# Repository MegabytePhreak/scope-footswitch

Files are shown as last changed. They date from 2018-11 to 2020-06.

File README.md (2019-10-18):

SCOPE-FOOTSWITCH
=================

STM32F401 based oscilloscope-footswitch interface using USBTMC.

Hardware is licensed CC-BY-SA-4.0
Software is GPLv3 for easy license compatibility with ChibiOS

Links:
* [Hackaday Coverage](https://hackaday.com/2018/12/02/keep-both-hands-on-the-probes-with-this-oscilloscope-footswitch/)
* [Initial Announcement](https://twitter.com/roukemap/status/1066811243237904384)
* [Rev.2 Batch](https://twitter.com/roukemap/status/1068734964215115776)
* [Custom Panels](https://twitter.com/roukemap/status/1072344658313908224)

Tools:

Other versions may work, this is just what is currently tested

HW:
* KiCAD 5.0.1

SW:
* arm-none-eabi-gcc (GNU Tools for ARM Embedded Processors 7-2018-q2-update) 7.3.1 20180622 (release) [ARM/embedded-7-branch revision 261907]
* GNU gdb (GNU Tools for ARM Embedded Processors 7-2018-q2-update) 8.1.0.20180315-git
* ChibiOS-RT with community USB Host framework
* libopencm3 and DFU code from BlackMagicProbe

This repo uses several submodules, make sure they are up to date.
After checking out the kicad-library repo, make sure to cd to it and run make to generate the actual KiCAD libraries.

SW Build Process:
1. Make sure the arm-none-eabi toolchain is on your path: `which arm-none-eabi-gcc`
2. Pre-build the libopencm3 library: `cd sw/ext/libopencm3 && make -j && cd ../../..`
3. Build the bootloader: `cd sw/bootloader && make -j && cd ../..`
4. Build the main application: `cd sw/scope-footswitch && make -j && cd ../..`

SW Programming process:
1. Connect SWD debugger (e.g. blackmagicprobe) to hardware
2. Connect micro-usb from pc to hardware
3. `cd sw/bootloader`
4. `./flash.sh`
5. Power cycle hardware, holding down the front panel button to force entry to the bootloader
6. `cd ../scope-footswitch`
7. `./dfu.sh`

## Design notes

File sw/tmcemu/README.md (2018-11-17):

TMCEMU
=======

STM32F072B-DISCO based USBTMC device with oscilloscope emulation

Tools:

* arm-none-eabi-gcc (GNU Tools for Arm Embedded Processors 7-2018-q2-update) 7.3.1 20180622 (release) [ARM/embedded-7-branch revision 261907]
* GNU gdb (GNU Tools for Arm Embedded Processors 7-2018-q2-update) 8.1.0.20180315-git
* ChibiOS-RT
* scpi-parser

This repo uses several submodules, make sure they are up to date.

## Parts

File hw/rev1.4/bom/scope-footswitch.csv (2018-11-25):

Source: | C:\Users\Megabytephreak\Code\scope-footswitch\hw\scope-footswitch.sch
Date: | 2018-11-19 0:04
Tool: | Eeschema (5.0.0)
Generator: | C:\Users\Megabytephreak\Code\scope-footswitch\hw\kicad-library\scripting/bom.py
Component Count: | 97
Item | Qty | Reference(s) | Value | LibPart | Footprint | Datasheet | BOM_IGNORE | COLOR | CREATED_ON | Capacitance | ComponentLink1Description | ComponentLink2Description | ComponentLink2URL | DNP | Description | Dielectric | Frequency | IF | Id | MANUFACTURER_PART_NUMBER | Manufacturer | NUMBER | Package | Power | Resistance | Supplier 1 | Supplier 2 | Supplier Part Number 1 | Supplier Part Number 2 | Tolerance | Type | VF | VR | Vdss | Vgsth | Voltage
1 | 18 | C1, C2, C3, C4, C7, C8, C13, C14, C15, C16, C17, C18, C19, C21, C22, C23, C27, C29 | C00001 | capacitors:C00001 | footprints:C_0402_1005M | http://search.murata.co.jp/Ceramy/image/img/PDF/ENG/GRM155R61A104KA01.pdf |  |  | 02/17/11 00:00:00 | 100n | Datasheet |  |  |  | CAP CER .1UF 10V 10% X5R 0402 | X5R |  |  |  | GRM155R61A104KA01D | Murata |  | 402 |  |  | Digi-key | Digi-key | 490-1318-2-ND | 490-1318-1-ND | ±10% |  |  |  |  |  | 10V
2 | 3 | C6, C20, C28 | C00002 | capacitors:C00002 | footprints:C_0603_1608M | http://search.murata.co.jp/Ceramy/image/img/PDF/ENG/GRM188R61A105KA61.pdf |  |  | 02/18/11 00:00:00 | 1µ | Datasheet |  |  |  | CAP CER 1.0UF 10V 10% X5R 0603 | X5R |  |  |  | GRM188R61A105KA61D | Murata |  | 603 |  |  | Digi-key | Digi-key | 490-1543-2-ND | 490-1543-2-ND | ±10% |  |  |  |  |  | 10V
3 | 2 | C9, C11 | C00033 | capacitors:C00033 | footprints:C_0402_1005M | http://search.murata.co.jp/Ceramy/image/img/A01X/G101/ENG/GRM1555C1H220JA01-01.pdf |  |  | 2008-04-17 0:00 | 22p | Spec Sheet |  |  |  | CAP CER 22PF 50V C0G/NP0 0402 | C0G |  |  |  | GRM1555C1H220JA01J | Murata |  | 402 |  |  | Digi-Key | Digi-Key | 490-11382-2-ND | 490-11382-1-ND | ±5% |  |  |  |  |  | 50V
4 | 1 | C10 | C00004 | capacitors:C00004 | footprints:C_0805_2012M | http://search.murata.co.jp/Ceramy/image/img/PDF/ENG/GRM21BR60J106ME19.pdf |  |  | 02/18/11 00:00:00 | 10µ | Datasheet |  |  |  | CAP CER 10UF 6.3V 20% X5R 0805 | X5R |  |  |  | GRM21BR60J106ME19L | Murata |  | 805 |  |  | Digi-key | Digi-key | 490-1718-2-ND | 490-1718-1-ND | ±20% |  |  |  |  |  | 6.3V
5 | 1 | C12 | C00007 | capacitors:C00007 | footprints:C_0603_1608M | http://search.murata.co.jp/Ceramy/image/img/PDF/ENG/GRM188R60J475ME19.pdf |  |  | 09/23/11 00:00:00 | 4u7 | Datasheet |  |  |  | CAP CER 4.7UF 6.3V X5R 0603 | X5R |  |  |  | GRM188R60J475ME19D | Murata |  | 603 |  |  | Digi-key | Digi-key | 490-5421-2-ND | 490-5421-1-ND | ±20% |  |  |  |  |  | 6.3V
6 | 1 | C24 | C00003 | capacitors:C00003 | footprints:CRADIAL_6.3x11.2_2.5 | http://industrial.panasonic.com/www-cgi/jvcr13pz.cgi?E+PZ+3+ABA0012+ECA1EM101+7+WW |  |  | 02/18/11 00:00:00 | 100µ | Component Page |  |  |  | CAP 100UF 25V ALUM LYTIC RADIA | Electrolytic |  |  |  | ECA-1EM101 | Panasonic |  | Radial |  |  | Digi-key |  | P5152-ND |  | ±20% |  |  |  |  |  | 25V
7 | 2 | C25, C26 | C00027 | capacitors:C00027 | footprints:C_0402_1005M | http://www.yageo.com/documents/recent/UPY-GP_NP0_16V-to-50V_10.pdf |  |  | 2008-02-18 0:00 | 4n7 | Datasheet |  |  |  | CAP CER 4700PF 50V X7R 0402 | X7R |  |  |  | 8.85012E+11 | Wurth |  | 402 |  |  | Digi-Key | Digi-Key | 732-7560-1-ND | 732-7560-2-ND | ±10% |  |  |  |  |  | 50V
8 | 1 | D2 | LED00006 | leds:LED00006 | footprints:LED_3535_NEOPIXEL_MINI | https://cdn-shop.adafruit.com/product-files/2686/SK6812MINI_REV.01-1-2.pdf |  | RGB | 04/29/16 00:00:00 |  | Datasheet |  |  |  | LED RGB, ADDRESSABLE, 3535 |  |  |  |  | SK6812MINI | DONGGUANG OPSCO OPTOELECTRONICS CO., LTD |  | 3535 |  |  | Digi-Key | Adafruit | 1528-1541-ND | 2686 |  |  |  |  |  |  | 5V
9 | 3 | D3, D4, D5 | D00003 | diodes:D00003 | footprints:SOT_6_950_2900X1600X1100 | http://www.st.com/web/en/resource/technical/document/datasheet/CD00047494.pdf |  |  | 07/18/15 00:00:00 |  | Datasheet |  |  |  | TVS DIODE 5.25VWM 17VC SOT23-6 |  |  | - |  | USBLC6-4SC6 | ST |  |  | - |  | Digi-Key |  | 497-4492-1-ND |  |  | TVS ARRAY | - | 6
10 | 1 | D6 | D00006 | diodes:D00006 | footprints:SOT_3_950_2900X1300X1000_ONSEMI | http://www.onsemi.com/pub/Collateral/BAT54CLT1-D.PDF |  |  | 09/23/18 00:00:00 |  | Datasheet |  |  |  | DIODE ARRAY SCHOTTKY 30V SOT23-3 |  |  | 200mA |  | BAT54CLT3G | ON Semiconductior |  |  | 225mQ |  | Digi-Key |  | BAT54CLT3GOSCT-ND |  |  | Array | 300mV @ 1MA | 30V
11 | 1 | J1 | CN00050 | connectors:CN00050 | footprints:J_CUI_SJ1-3533NG | https://www.cui.com/product/resource/digikeypdf/sj1-353xng.pdf |  |  | 07/29/18 00:00:00 |  | Drawing |  |  |  | CONN JACK STEREO 3.5MM R/A |  |  |  |  | SJ1-3533NG | CUI |  |  |  |  | Digi-Key |  | CP1-3533NG-ND
12 | 1 | J2 | CN00049 | connectors:CN00049 | footprints:J_AMPHENOL_UE27AC54100 | https://www.amphenolcanada.com/ProductSearch/drawings/AC/UE27ACX4X0X.pdf |  |  | 07/28/18 00:00:00 |  | Drawing |  |  |  | CONN RCPT USB TYPE A R/A GOLD |  |  |  |  | UE27AC54100 | Amphenol |  |  |  |  | Digi-Key |  | UE27AC54100-ND
13 | 1 | J3 | CN00023 | connectors:CN00023 | footprints:J_FCI_10118194 | http://portal.fciconnect.com/Comergent//fci/drawing/10118194.pdf |  |  | 2001-02-15 0:00 |  | Drawing |  |  |  | CONN USB MICRO B RECPT SMT R/A |  |  |  |  | 10118194-0001LF | FCI |  |  |  |  | Digi-Key |  | 609-4618-1-ND
14 | 1 | P1 | CN00052 | connectors:CN00052 | footprints:P_FCI_68000-206 | http://portal.fciconnect.com/Comergent//fci/drawing/68000.pdf |  |  | 07/31/18 00:00:00 |  | Drawing |  |  |  | BERGSTIK II 6POS .100" SR STRAIGHT |  |  |  |  | 68000-206HLF | FCI |  |  |  |  | Digi-Key |  | 609-3256-ND
15 | 1 | P2 | CN00051 | connectors:CN00051 | footprints:P_CNC_3221-10-0300-00 | http://cnctech.us/pdfs/3221-XX-0300-00.pdf |  |  | 07/30/18 00:00:00 |  | Drawing |  |  |  | IDC BOX HEADER .050" 10 POS |  |  |  |  | 3221-10-0300-00 | CNC Tech |  |  |  |  | Digi-Key |  | 1175-1735-ND
16 | 1 | Q1 | Q00002 | transistors:Q00002 | footprints:SOT_6_650_2150X1300x1100_DIODES | http://www.diodes.com/datasheets/DMN63D8LDW.pdf |  |  | 2007-08-15 0:00 |  | Datasheet |  |  |  | MOSFET 2N-CH 30V 220MA SOT363 |  |  |  | 220mA | DMN63D8LDW-7 | Diodes Inc | 2 |  | 300mW |  | Digi-Key |  | DMN63D8LDW-7CT-ND |  |  | N-FET |  |  | 30V | 1.5V
17 | 18 | R1, R4, R5, R8, R13, R18, R21, R22, R23, R24, R25, R26, R27, R28, R30, R32, R33, R41 | R00014 | resistors:R00014 | footprints:R_0402_1005M | http://www.yageo.com/documents/recent/PYu-RC0402_51_RoHS_L_6.pdf |  |  | 09/23/11 00:00:00 |  | Series Datasheet |  |  |  | RES 10.0K OHM 1/16W 1% 0402 SMD |  |  |  |  | RC0402FR-0710KL | Yageo |  | 402 | 1/16W | 10K | Digi-key | Digi-key | 311-10.0KLRTR-ND | 311-10.0KLRCT-ND | 1% | Thick Film
18 | 3 | R2, R3, R35 | R00016 | resistors:R00016 | footprints:R_0402_1005M | http://www.yageo.com/documents/recent/PYu-RC0402_51_RoHS_L_6.pdf |  |  | 09/25/11 00:00:00 |  | Series Datasheet |  |  |  | RES 100K OHM 1/16W 5% 0402 SMD |  |  |  |  | RC0402JR-07100KL | Yageo |  | 402 | 1/16W | 100K | Digi-key | Digi-key | 311-100KJRTR-ND | 311-100KJRCT-ND | 1% | Thick Film
19 | 1 | R7 | R00056 | resistors:R00056 | footprints:R_0402_1005M | http://www.yageo.com/documents/recent/PYu-RC0402_51_RoHS_L_6.pdf |  |  | 2008-05-17 0:00 |  | Series Datasheet |  |  |  | RES SMD 15K OHM 1% 1/16W 0402 |  |  |  |  | RC0402FR-0715KL | Yageo |  | 402 | 1/16W | 15K | Digi-key | Digi-key | 311-15K0LRTR-ND | 311-15K0LRCT-ND | 1% | Thick Film
20 | 1 | R9 | R00037 | resistors:R00037 | footprints:R_0402_1005M | http://www.yageo.com/documents/recent/PYu-RC0402_51_RoHS_L_6.pdf |  |  | 07/24/17 00:00:00 |  | Series Datasheet |  |  |  | RES 240 OHM 1/16W 1% 0402 SMD |  |  |  |  | RC0402FR-07240R1L | Yageo |  | 402 | 1/16W | 240R | Digi-key | Digi-key | 311-240LRTR-ND | 311-240LRCT-ND | 1% | Thick Film
21 | 1 | R14 | R00009 | resistors:R00009 | footprints:R_0402_1005M | http://www.yageo.com/documents/recent/PYu-RC0402_51_RoHS_L_6.pdf |  |  | 08/21/11 00:00:00 |  | Series Datasheet |  |  |  | RES 56K OHM 1/16W 5% 0402 SMD |  |  |  |  | RC0402JR-0756KL | Yageo |  | 402 | 1/16W | 56K | Digi-key | Digi-key | 311-56KJRTR-ND | 311-56KJRCT-ND | 5% | Thick Film
22 | 2 | R19, R20 | R00011 | resistors:R00011 | footprints:R_0402_1005M | http://www.yageo.com/documents/recent/PYu-RC0402_51_RoHS_L_6.pdf |  |  | 09/23/11 00:00:00 |  | Series Datasheet |  |  |  | RES 100 OHM 1/16W 1% 0402 SMD |  |  |  |  | RC0402FR-07100RL | Yageo |  | 402 | 1/16W | 100R | Digi-key | Digi-key | 311-100LRTR-ND | 311-100LRCT-ND | 1% | Thick Film
23 | 2 | R29, R31 | R00080 | resistors:R00080 | footprints:R_0603_1608M | https://www.seielect.com/Catalog/SEI-RMCF_RMCP.pdf |  |  | 09/20/18 00:00:00 |  | Series Datasheet |  |  |  | RES 64.9 OHM 1% 1/10W 0603 |  |  |  |  | RMCF0603FT64R9 | Stackpole |  | 603 | 1/10W | 64R9 | Digi-key | Digi-key | RMCF0603FT64R9TR-ND | RMCF0603FT64R9CT-ND | 1% | Thick Film
24 | 2 | R39, R40 | R00008 | resistors:R00008 | footprints:R_0402_1005M | http://www.yageo.com/documents/recent/PYu-RC0402_51_RoHS_L_6.pdf |  |  | 08/20/11 00:00:00 |  | Series Datasheet |  |  |  | RES 1.0M OHM 1/16W 5% 0402 SMD |  |  |  |  | RC0402JR-071ML | Yageo |  | 402 | 1/16W | 1M | Digi-key | Digi-key | 311-1.0MJRTR-ND | 311-1.0MJRCT-ND | 5% | Thick Film
25 | 1 | R42 | R00001 | resistors:R00001 | footprints:R_0402_1005M | http://www.seielect.com/Catalog/SEI-RMC.pdf |  |  | 02/17/11 00:00:00 |  | Series Datasheet |  |  |  | RES 0.0 OHM 1/16W 0402 SMD |  |  |  |  | RMCF0402ZT0R00 | Stackpole Electronics |  | 402 | 1/16W | 0R | Digi-key | Digi-key | RMCF0402ZT0R00TR-ND | RMCF0402ZT0R00CT-ND |  | Thick Film
26 | 1 | SW1 | M00027 | misc:M00027 | footprints:SW_NKK_G13AV | http://www.nkkswitches.com/pdf/Gtoggles.pdf | 0 |  | 07/18/29 00:00:00 |  | Series Datasheet |  |  |  | SWITCH TOGGLE SPDT 0.4VA 28V |  |  |  |  | G13AV | NKK Switches |  |  |  |  | Digi-Key |  | 360-1770-ND
27 | 1 | SW2 | M00012 | misc:M00012 | footprints:SW_TL1105JA | http://spec_sheets.e-switch.com/specs/P010205.pdf | 0 |  | 2007-05-15 0:00 |  | Drawing | Series Datasheet | https://www.e-switch.com/system/asset/product_line/data_sheet/140/TL1105.pdf |  | SWITCH TACTILE SPST-NO 0.05A 12V |  |  |  |  | TL1105JAF160Q | E-Switch |  |  |  |  | Digi-Key |  | EG1863-ND
28 | 1 | SW3 | M00026 | misc:M00026 | footprints:SW_NKK_G12JVCF | http://www.nkkswitches.com/pdf/gtogglesilluminated.pdf | 0 |  | 07/29/18 00:00:00 |  | Series Datasheet |  |  |  | SWITCH ILLUMINATED TOGGLE SPDT 0.4VA 28V |  |  |  |  | G12JVCF | NKK Switches |  |  |  |  | Digi-Key |  | 360-1765-ND
29 | 1 | U1 | U00054 | ics:U00054 | footprints:SOT_5_950_2900X1600X1100_DIODES | http://www.diodes.com/_files/datasheets/74AHCT1G125.pdf |  |  | 04/29/16 00:00:00 |  | Datasheet |  |  |  | 74AHCT1G125W5-7 |  |  |  |  | 74AHCT1G125W5-7 | Diodes |  |  |  |  | Digi-Key |  | 74AHCT1G125W5-7DICT-ND
30 | 2 | U2, U8 | U00086 | ics:U00086 | footprints:SOT_6_950_2800x1600x110_DIODES_SOT26 | https://www.diodes.com/assets/Datasheets/AP255x.pdf |  |  | 07/29/18 00:00:00 |  | Datasheet |  |  |  | IC PD SW CURR LIMIT SOT26 |  |  |  |  | AP2553AW6-7 | Diodes |  |  |  |  | Digi-Key |  | AP2553AW6-7DICT-ND
31 | 1 | U5 | U00049 | ics:U00049 | footprints:SOT_5_950_2900X1600X1100_DIODES | http://www.diodes.com/datasheets/AP2138_9.pdf |  |  | 2001-03-15 0:00 |  | Datasheet |  |  |  | IC REG LDO 3.3V 0.25A SOT25 |  |  |  |  | AP2139AK-3.3TRG1 | Diodes |  |  |  |  | Digi-Key |  | AP2139AK-3.3TRG1DICT-ND
32 | 1 | U6 | U00084 | ics:U00084 | footprints:QFN_48_500_7000X7000X600_ST | http://www.st.com/content/ccc/resource/technical/document/datasheet/9e/50/b1/5a/5f/ae/4d/c1/DM00086815.pdf/files/DM00086815.pdf/jcr:content/translations/en.DM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 |  |  | 07/28/18 00:00:00 |  | Datasheet |  |  |  | IC MCU 32BIT 128KB FLASH 48QFPN |  |  |  |  | STM32F401CBU6 | ST |  |  |  |  | Digi-Key |  | 497-17425-ND
33 | 1 | U7 | U00085 | ics:U00085 | footprints:MSOP_10_500_3000X3000X1100_ONSEMI | https://www.fairchildsemi.com/datasheets/FS/FSUSB42.pdf |  |  | 07/28/18 00:00:00 |  | Datasheet |  |  |  | IC USB SWITCH DPDT 10MSOP |  |  |  |  | FSUSB42MUX | ONSEMI |  |  |  |  | Digi-Key |  | FSUSB42MUXCT-ND
34 | 1 | Y1 | Y00015 | crystals:Y00015 | footprints:XTAL_2_5000X3200X1300_ABRACON | https://abracon.com/Resonators/abm3.pdf |  |  | 07/29/18 00:00:00 | 18pF | Datasheet |  |  |  | CRYSTAL 8.0000MHZ 18PF SMD |  | 8 MHz |  |  | ABM3-8.000MHZ-D2Y-T | Abracon |  | 5mm x 3.2mm |  |  | Digi-Key |  | 535-10630-1-ND |  | 20ppm | Crystal
35 | 1 | C5 | C00001 | capacitors:C00001 | footprints:C_0402_1005M | http://search.murata.co.jp/Ceramy/image/img/PDF/ENG/GRM155R61A104KA01.pdf |  |  | 02/17/11 00:00:00 | 100n | Datasheet |  |  | DNP | CAP CER .1UF 10V 10% X5R 0402 | X5R |  |  |  | GRM155R61A104KA01D | Murata |  | 402 |  |  | Digi-key | Digi-key | 490-1318-2-ND | 490-1318-1-ND | ±10% |  |  |  |  |  | 10V
36 | 1 | D1 | D00006 | diodes:D00006 | footprints:SOT_3_950_2900X1300X1000_ONSEMI | http://www.onsemi.com/pub/Collateral/BAT54CLT1-D.PDF |  |  | 09/23/18 00:00:00 |  | Datasheet |  |  | DNP | DIODE ARRAY SCHOTTKY 30V SOT23-3 |  |  | 200mA |  | BAT54CLT3G | ON Semiconductior |  |  | 225mQ |  | Digi-Key |  | BAT54CLT3GOSCT-ND |  |  | Array | 300mV @ 1MA | 30V
37 | 5 | R6, R11, R15, R16, R17 | R00014 | resistors:R00014 | footprints:R_0402_1005M | http://www.yageo.com/documents/recent/PYu-RC0402_51_RoHS_L_6.pdf |  |  | 09/23/11 00:00:00 |  | Series Datasheet |  |  | DNP | RES 10.0K OHM 1/16W 1% 0402 SMD |  |  |  |  | RC0402FR-0710KL | Yageo |  | 402 | 1/16W | 10K | Digi-key | Digi-key | 311-10.0KLRTR-ND | 311-10.0KLRCT-ND | 1% | Thick Film
38 | 2 | R10, R12 | R00038 | resistors:R00038 | footprints:R_0402_1005M | http://www.yageo.com/documents/recent/PYu-RC0402_51_RoHS_L_6.pdf |  |  | 07/24/17 00:00:00 |  | Series Datasheet |  |  | DNP | RES 4.7K OHM 1/16W 1% 0402 SMD |  |  |  |  | RC0402FR-074K7L | Yageo |  | 402 | 1/16W | 4K7 | Digi-key | Digi-key | 311-4.7KTR-ND | 311-4.7KLRCT-ND | 1% | Thick Film
39 | 2 | R34, R37 | R00081 | resistors:R00081 | footprints:R_0402_1005M | https://www.seielect.com/Catalog/SEI-RMCF_RMCP.pdf |  |  | 09/30/18 00:00:00 |  | Series Datasheet |  |  | DNP | RES 1.5K OHM 1% 1/16W 0402 |  |  |  |  | RMCF0402FT1K50 | Stackpole |  | 402 | 1/16W | 1K5 | Digi-key | Digi-key | RMCF0402FT1K50TR-ND | RMCF0402FT1K50CT-ND | 1% | Thick Film
40 | 2 | R36, R38 | R00056 | resistors:R00056 | footprints:R_0402_1005M | http://www.yageo.com/documents/recent/PYu-RC0402_51_RoHS_L_6.pdf |  |  | 2008-05-17 0:00 |  | Series Datasheet |  |  | DNP | RES SMD 15K OHM 1% 1/16W 0402 |  |  |  |  | RC0402FR-0715KL | Yageo |  | 402 | 1/16W | 15K | Digi-key | Digi-key | 311-15K0LRTR-ND | 311-15K0LRCT-ND | 1% | Thick Film
41 | 1 | R43 | R00046 | resistors:R00046 | footprints:R_0402_1005M | http://www.yageo.com/documents/recent/PYu-RC0402_51_RoHS_L_6.pdf |  |  | 2008-01-17 0:00 |  | Series Datasheet |  |  | DNP | RES 10K OHM 1/16W 1% 0402 SMD |  |  |  |  | RC0402FR-0710KL | Yageo |  | 402 | 1/16W | 10K | Digi-key | Digi-key | 311-10.0KLRTR-ND | 311-10.0KLRCT-ND | 1% | Thick Film
42 | 1 | R44 | R00001 | resistors:R00001 | footprints:R_0402_1005M | http://www.seielect.com/Catalog/SEI-RMC.pdf |  |  | 02/17/11 00:00:00 |  | Series Datasheet |  |  | DNP | RES 0.0 OHM 1/16W 0402 SMD |  |  |  |  | RMCF0402ZT0R00 | Stackpole Electronics |  | 402 | 1/16W | 0R | Digi-key | Digi-key | RMCF0402ZT0R00TR-ND | RMCF0402ZT0R00CT-ND |  | Thick Film
43 | 1 | U3 | U00055 | ics:U00055 | footprints:SOIC_8_1270_4900X3900X1750 | http://www2.st.com/content/ccc/resource/technical/document/datasheet/b0/d8/50/40/5a/85/49/6f/DM00071904.pdf/files/DM00071904.pdf/jcr:content/translations/en.D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 |  |  | 04/29/16 00:00:00 |  | Datasheet |  |  | DNP | IC EEPROM 2KBIT 400KHZ 8SOIC |  |  |  |  | M24C02-FMN6TP | ST |  |  |  |  | Digi-Key |  | 497-15748-1-ND
44 | 1 | U4 | U00087 | ics:U00087 | footprints:SOT_5_950_2900X1600X1100_DIODES | https://www.diodes.com/assets/Datasheets/74AHCT1G08.pdf |  |  | 2008-05-18 0:00 |  | Datasheet |  |  | DNP | IC GATE AND 1CH 2-INP SOT25 |  |  |  |  | 74AHCT1G08W5-7 | Diodes |  |  |  |  | Digi-Key |  | 74AHCT1G08W5-7DICT-ND

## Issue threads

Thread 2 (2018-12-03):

Dictaphone footswitch

sbridger, 2018-12-03:
Look for Dictaphone footswitches. They commonly have 3 switches, and are very well designed for foot operation - better than the generic little metal single switch plate.

I have wired a couple up to old usb keyboard controllers to control production test software

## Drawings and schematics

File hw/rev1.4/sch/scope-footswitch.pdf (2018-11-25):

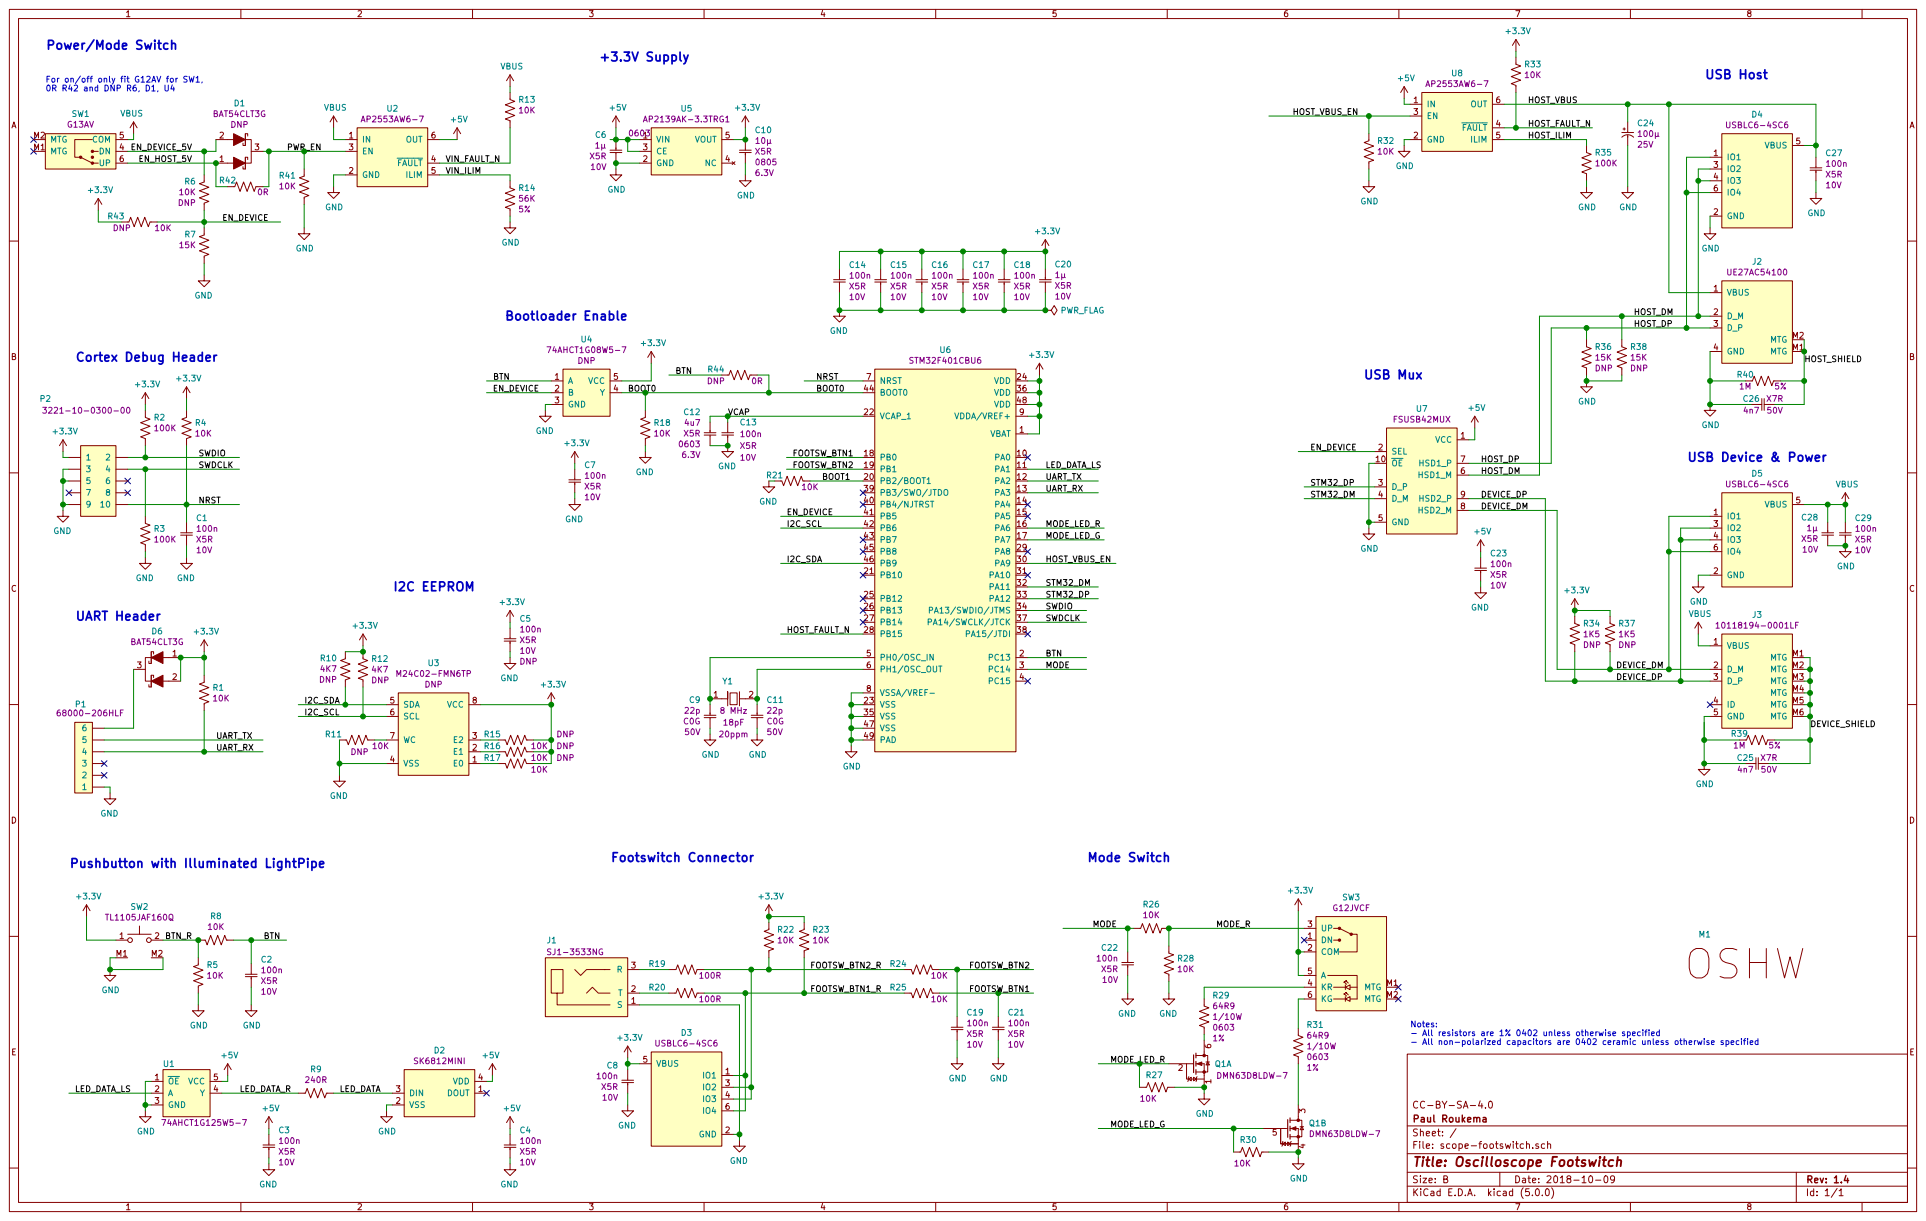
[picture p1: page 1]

For on/off only fit G12AV for SW1, 0R R42 and DNP R6, D1, U4 +3.3V

UART Header
HOST_FAULT_N Pushbutton with Illuminated LightPipe

Notes: - All resistors are 1% 0402 unless otherwise specified
- All non-polarized capacitors are 0402 ceramic unless otherwise specified

File: scope-footswitch.sch Sheet: / Paul Roukema CC-BY-SA-4.0

Id: 1/1 Title: Oscilloscope Footswitch

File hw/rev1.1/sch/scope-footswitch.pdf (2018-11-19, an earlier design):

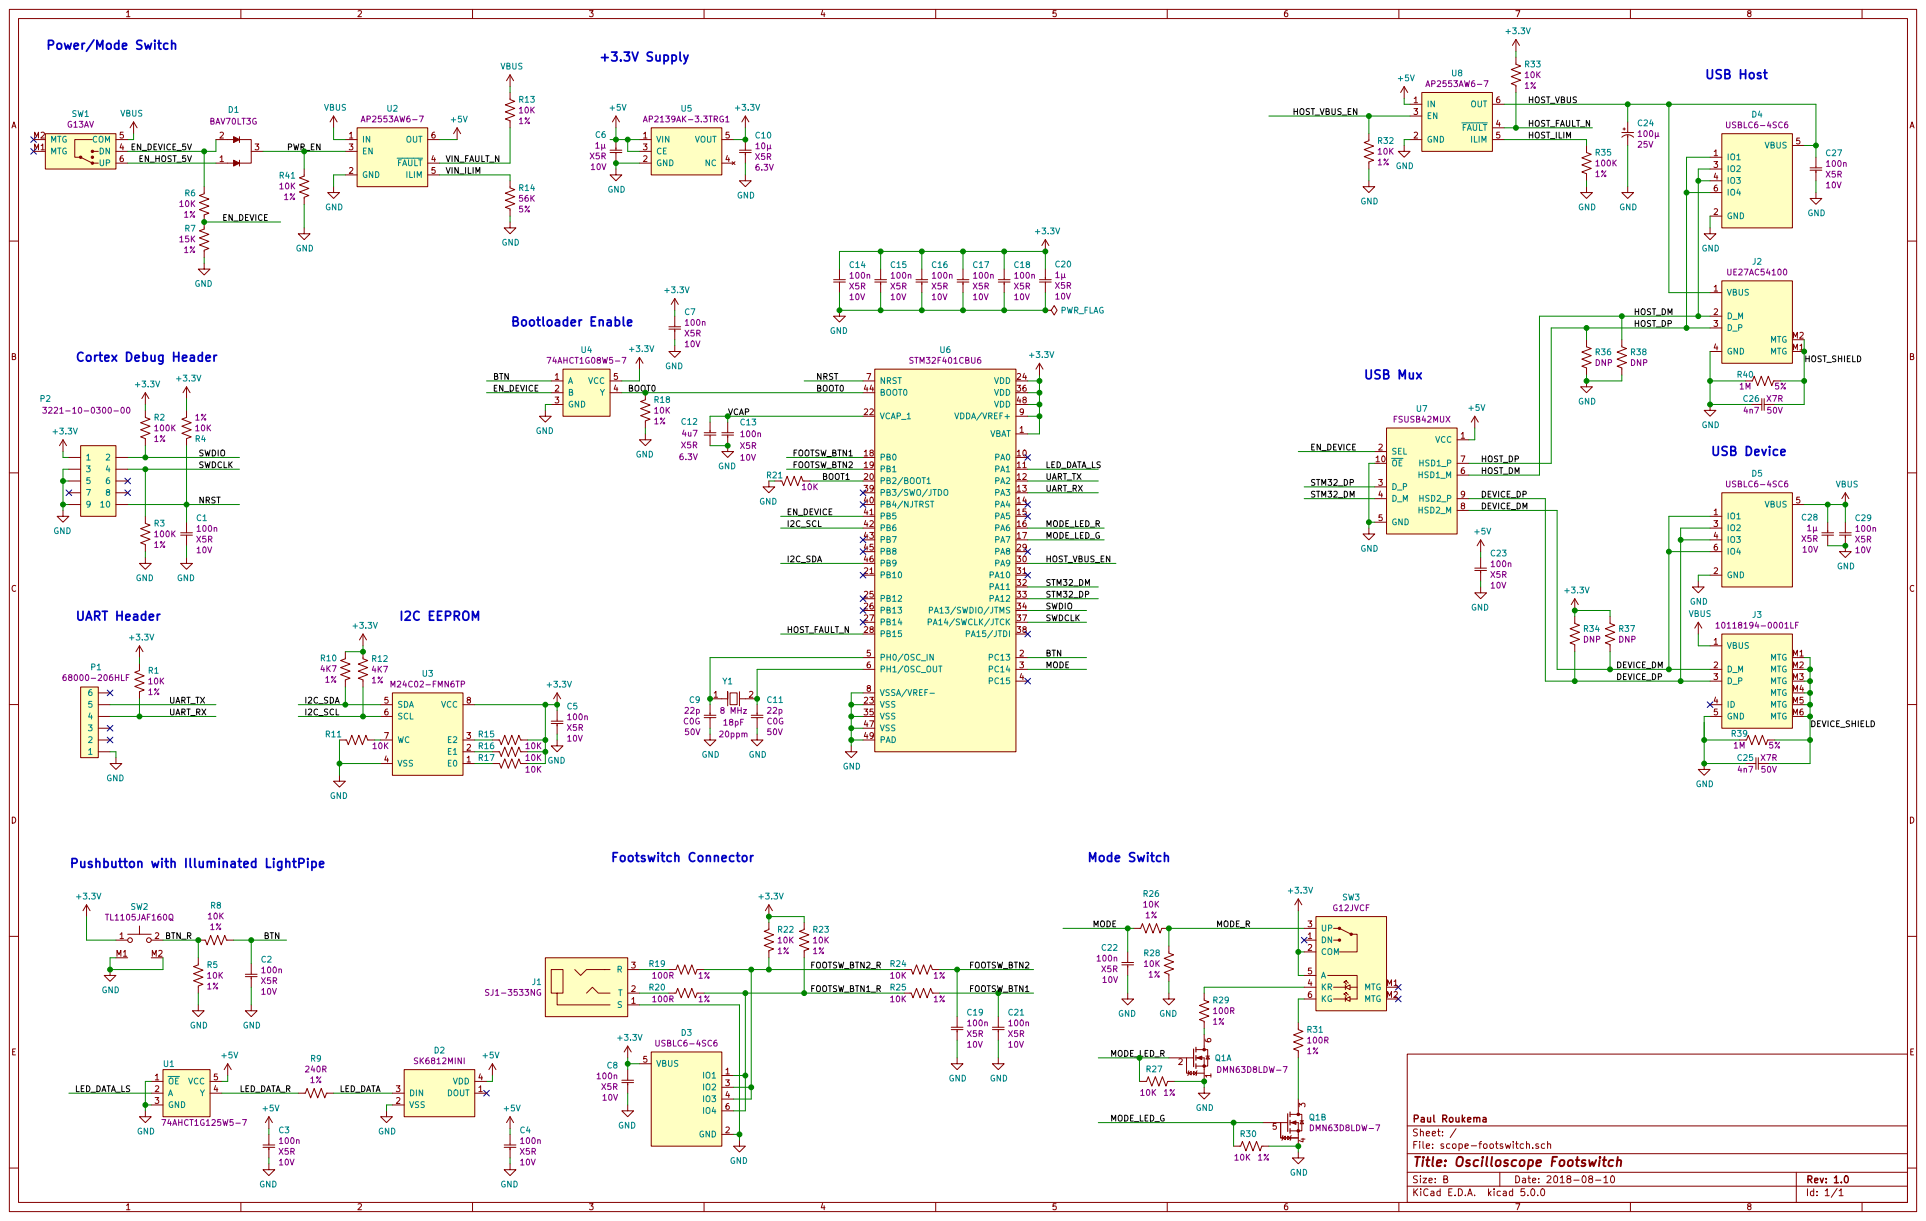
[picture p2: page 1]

UART Header
HOST_FAULT_N Pushbutton with Illuminated LightPipe

File: scope-footswitch.sch Sheet: / Paul Roukema

Id: 1/1 Title: Oscilloscope Footswitch

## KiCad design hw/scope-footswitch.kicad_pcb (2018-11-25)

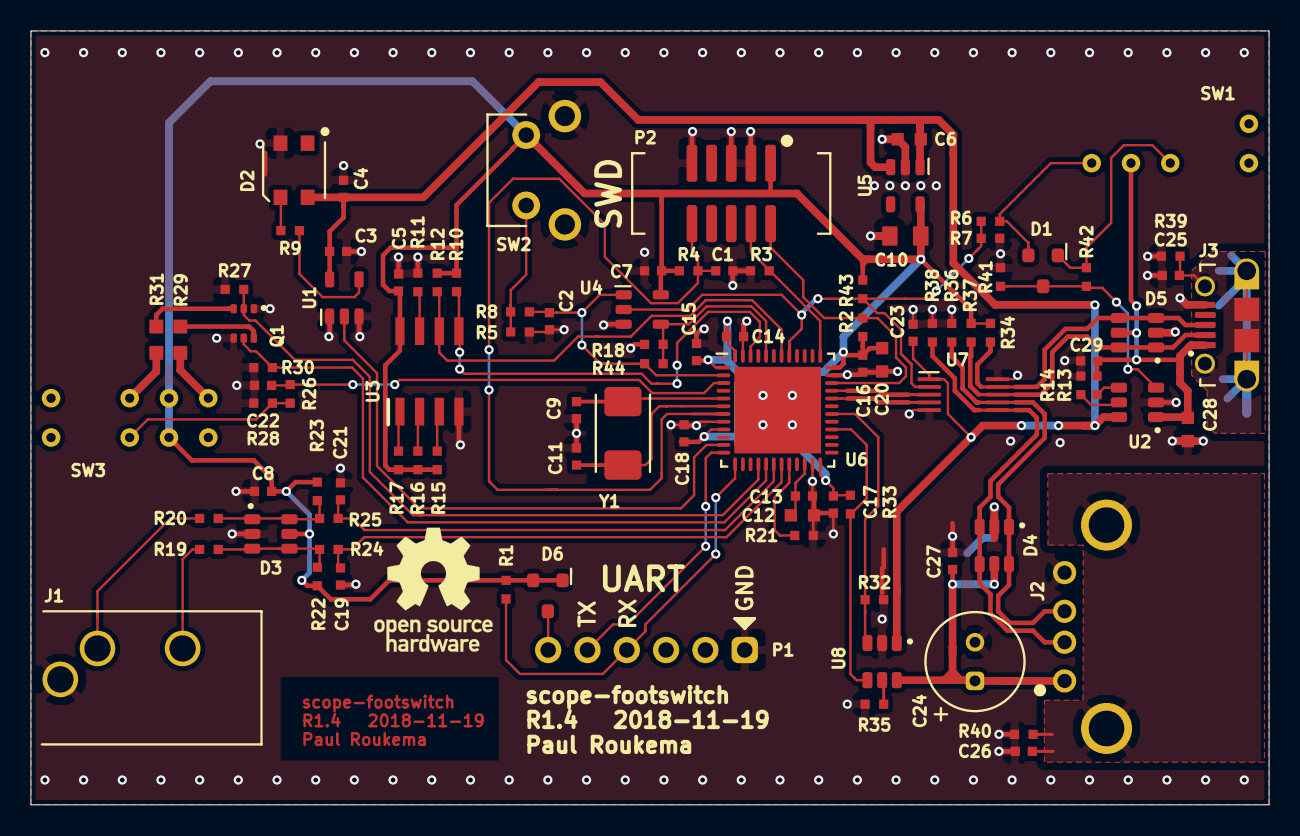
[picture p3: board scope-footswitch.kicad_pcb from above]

Board: 2 copper layers, 80.0 x 50.0 mm, 98 parts (0 on the bottom side), 58 nets.

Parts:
C1, C2, C3, C4, C5, C7, C8, C13, C14, C15, C16, C17, C18, C19, C21, C22, C23, C27, C29: C00001; C_0402_1005M
C6, C20, C28: C00002; C_0603_1608M
C9, C11: C00033; C_0402_1005M
C10: C00004; C_0805_2012M
C12: C00007; C_0603_1608M
C24: C00003; CRADIAL_6.3x11.2_2.5
C25, C26: C00027; C_0402_1005M
D1, D6: D00006; SOT_3_950_2900X1300X1000_ONSEMI
D2: LED00006; LED_3535_NEOPIXEL_MINI
D3, D4, D5: D00003; SOT_6_950_2900X1600X1100
J1: CN00050; J_CUI_SJ1-3533NG
J2: CN00049; J_AMPHENOL_UE27AC54100
J3: CN00023; J_FCI_10118194
M1: M00028; OSHW-Logo_7.5x8mm_SilkScreen
P1: CN00052; P_FCI_68000-206
P2: CN00051; P_CNC_3221-10-0300-00
Q1: Q00002; SOT_6_650_2150X1300x1100_DIODES
R1, R4, R5, R6, R8, R11, R13, R15, R16, R17, R18, R21, R22, R23, R24, R25, R26, R27, R28, R30, R32, R33, R41: R00014; R_0402_1005M
R2, R3, R35: R00016; R_0402_1005M
R7, R36, R38: R00056; R_0402_1005M
R9: R00037; R_0402_1005M
R10, R12: R00038; R_0402_1005M
R14: R00009; R_0402_1005M
R19, R20: R00011; R_0402_1005M
R29, R31: R00080; R_0603_1608M
R34, R37: R00081; R_0402_1005M
R39, R40: R00008; R_0402_1005M
R42, R44: R00001; R_0402_1005M
R43: R00046; R_0402_1005M
SW1: M00027; SW_NKK_G13AV
SW2: M00012; SW_TL1105JA
SW3: M00026; SW_NKK_G12JVCF
U1: U00054; SOT_5_950_2900X1600X1100_DIODES
U2, U8: U00086; SOT_6_950_2800x1600x110_DIODES_SOT26
U3: U00055; SOIC_8_1270_4900X3900X1750
U4: U00087; SOT_5_950_2900X1600X1100_DIODES
U5: U00049; SOT_5_950_2900X1600X1100_DIODES
U6: U00084; QFN_48_500_7000X7000X600_ST
U7: U00085; MSOP_10_500_3000X3000X1100_ONSEMI
Y1: Y00015; XTAL_2_5000X3200X1300_ABRACON

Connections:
+3V3: C5.1, C7.1, C8.1, C10.1, C14.1, C15.1, C16.1, C17.1, C18.1, C20.2, D3.5, D6.1, D6.2, P2.1, R1.1, R2.1, R4.1, R10.2, R12.1, R15.2, R16.2, R17.2, R22.1, R23.1, R33.1, R34.1, R37.1, R43.2, SW2.1, SW3.2, SW3.5, U3.8, U4.5, U5.5, U6.1, U6.9, U6.24, U6.36, U6.48
+5V: C3.1, C4.1, C6.2, C23.1, D2.4, U1.5, U2.6, U5.1, U5.3, U7.1, U8.1
/BOOT0: R18.1, R44.1, U4.4, U6.44
/BOOT1: R21.2, U6.20
/BTN: C2.1, R8.2, R44.2, U4.1, U6.2
/BTN_R: R5.1, R8.1, SW2.2
/DEVICE_DM: D5.1, D5.6, J3.2, R37.2, U7.8
/DEVICE_DP: D5.3, D5.4, J3.3, R34.2, U7.9
/DEVICE_SHIELD: C25.1, J3.M1, J3.M2, J3.M3, J3.M4, J3.M5, J3.M6, R39.2
/EN_DEVICE: R6.1, R7.2, R43.1, U4.2, U6.41, U7.2
/EN_DEVICE_5V: D1.2, R6.2, SW1.4
/EN_HOST_5V: D1.1, R42.1, SW1.6
/FOOTSW_BTN1: C21.1, R25.2, U6.18
/FOOTSW_BTN1_R: D3.1, D3.6, R20.1, R23.2, R25.1
/FOOTSW_BTN2: C19.1, R24.2, U6.19
/FOOTSW_BTN2_R: D3.3, D3.4, R19.1, R22.2, R24.1
/HOST_DM: D4.3, D4.4, J2.2, R38.1, U7.6
/HOST_DP: D4.1, D4.6, J2.3, R36.1, U7.7
/HOST_FAULT_N: R33.2, U6.28, U8.4
/HOST_ILIM: R35.1, U8.5
/HOST_SHIELD: C26.1, J2.M1, J2.M2, R40.2
/HOST_VBUS: C24.+, C27.1, D4.5, J2.1, U8.6
/HOST_VBUS_EN: R32.1, U6.30, U8.3
/I2C_SCL: R12.2, U3.6, U6.42
/I2C_SDA: R10.1, U3.5, U6.46
/LED_DATA: D2.3, R9.1
/LED_DATA_LS: U1.2, U6.11
/LED_DATA_R: R9.2, U1.4
/MODE: C22.1, R26.2, U6.3
/MODE_LED_G: Q1.5, R30.1, U6.17
/MODE_LED_R: Q1.2, R27.1, U6.16
/MODE_R: R26.1, R28.1, SW3.3
/NRST: C1.1, P2.10, R4.2, U6.7
/PWR_EN: D1.3, R41.2, R42.2, U2.3
/STM32_DM: U6.32, U7.4
/STM32_DP: U6.33, U7.3
/SWDCLK: P2.4, R3.1, U6.37
/SWDIO: P2.2, R2.2, U6.34
/UART_RX: P1.4, R1.2, U6.13
/UART_TX: P1.5, U6.12
/VCAP: C12.2, C13.1, U6.22
/VIN_FAULT_N: R13.2, U2.4
/VIN_ILIM: R14.1, U2.5
GND: C1.2, C2.2, C3.2, C4.2, C5.2, C6.1, C7.2, C8.2, C9.1, C10.2, C11.1, C12.1, C13.2, C14.2, C15.2, C16.2, C17.2, C18.2, C19.2, C20.1, C21.2, C22.2, C23.2, C24.-, C25.2, C26.2, C27.2, C28.1, C29.2, D2.2, D3.2, D4.2, D5.2, J1.1, J2.4, J3.5, P1.1, P2.3, P2.5, P2.9, Q1.1, Q1.4, R3.2, R5.2, R7.1, R11.1, R14.2, R18.2, R21.1, R27.2, R28.2, R30.2, R32.2, R35.2, R36.2, R38.2, R39.1, R40.1, R41.1, SW2.M1, SW2.M2, U1.1, U1.3, U2.2, U3.4, U4.3, U5.2, U6.8, U6.23, U6.35, U6.47, U6.49, U7.5, U7.10, U8.2
unnamed: C9.2, U6.5, Y1.1
unnamed: C11.2, U6.6, Y1.2
unnamed: D6.3, P1.6
unnamed: J1.2, R20.2
unnamed: J1.3, R19.2
unnamed: Q1.3, R31.2
unnamed: Q1.6, R29.2
unnamed: R11.2, U3.7
unnamed: R15.1, U3.3
unnamed: R16.1, U3.2
unnamed: R17.1, U3.1
unnamed: R29.1, SW3.4
unnamed: R31.1, SW3.6
VBUS: C28.2, C29.1, D5.5, J3.1, R13.1, SW1.5, U2.1

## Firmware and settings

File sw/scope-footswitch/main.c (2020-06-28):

/*
 * This file is part of the scope-footswitch project.
 *
 * Copyright (C) 2018 Paul Roukema <paul@paulroukema.com>
 *
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
 * You should have received a copy of the GNU General Public License
 * along with this program.  If not, see <http://www.gnu.org/licenses/>.
 */


#include "ch.h"
#include "hal.h"
#include "chprintf.h"
#include "usbh/debug.h" /* for usbDbgPuts/usbDbgPrintf */
#include <string.h>

#include "events.h"
#include "led_manager.h"
#include "scope.h"
#include "usbh_usbtmc.h"
#include "ws2812.h"
#include "image_header.h"

#define PWM_FREQ 2000
static PWMConfig tim3_pwmcfg = {
    STM32_SYSCLK, /* PWM clock frequency, PSC register. */
    (uint16_t)(STM32_SYSCLK / PWM_FREQ) +
        1, /* Initial PWM period. ARR register*/
    NULL,  /* Periodic callback pointer. */
    {      /* Channel configuration set dynamically below, */
     {PWM_OUTPUT_ACTIVE_HIGH | PWM_COMPLEMENTARY_OUTPUT_ACTIVE_LOW, NULL},
     {PWM_OUTPUT_ACTIVE_HIGH | PWM_COMPLEMENTARY_OUTPUT_ACTIVE_LOW, NULL},
     {PWM_OUTPUT_DISABLED, NULL},
     {PWM_OUTPUT_DISABLED, NULL}},
    0, /* TIM CR2 register initialization data. */
#if STM32_PWM_USE_ADVANCED
    0, /* TIM BDTR register initialization data. */
#endif
    0};

static uint32_t ws2812_buffer[WS2812_BUFFER_SIZE(1)];

static WS2812Config ws2812_config = {STM32_SYSCLK,
                                     &PWMD5,
                                     1,
                                     STM32_DMA1_STREAM4,
                                     6,
                                     &ws2812_buffer[0],
                                     WS2812_TIMING_CONFIG(STM32_SYSCLK),
                                     {}};

#define LED_MODE_GREEN 1
#define LED_MODE_RED 0

static LedManagerEntry g_leds[] = {
    {&PWMD3, 0, LED_MODE_REMAP, 0, 0, 5000, 1000},
    {&PWMD3, 1, LED_MODE_REMAP, 0, 0, 9000, 1000},
};

static LedManagerWS2812 g_rgb_leds[] = {
    {LED_MODE_REMAP, {WS2812_RED}, 3000, 500, 3000, 200},
};

static WS2812Pixel ws2812_pixel_buf[1];

static LedManagerConfig led_config = {g_leds,
                                      &logarithmicLedRemap,
                                      sizeof(g_leds) / sizeof(g_leds[0]),
                                      10,
                                      &ws2812_config,
                                      g_rgb_leds,
                                      sizeof(g_rgb_leds) /
                                          sizeof(g_rgb_leds[0]),
                                      ws2812_pixel_buf};

static THD_WORKING_AREA(waThreadLed, 1024);
static THD_FUNCTION(ThreadLed, arg) {
    (void)arg;

    pwmStart(&PWMD3, &tim3_pwmcfg);
    // pwmStart(&PWMD5, &tim5_pwmcfg);
    ws2812_init(&ws2812_config);
    pwmEnableChannel(&PWMD3, 0, PWM_PERCENTAGE_TO_WIDTH(&PWMD3, 5000));
    pwmEnableChannel(&PWMD3, 1, PWM_PERCENTAGE_TO_WIDTH(&PWMD3, 5000));

    runLedManager(&led_config);
}

static void update_leds(scope_state_t state) {
    switch (state) {
        case SCOPE_STATE_RUNNING:
            setLedTarget(&led_config, FALSE, LED_MODE_GREEN, 10000);
            setLedTarget(&led_config, FALSE, LED_MODE_RED, 0);
            break;
        case SCOPE_STATE_SINGLE:
            setLedTarget(&led_config, FALSE, LED_MODE_GREEN, 10000);
            setLedTarget(&led_config, FALSE, LED_MODE_RED, 6000);
            break;
        case SCOPE_STATE_STOPPED:
            setLedTarget(&led_config, FALSE, LED_MODE_GREEN, 0);
            setLedTarget(&led_config, FALSE, LED_MODE_RED, 10000);
            break;
        default:
            setLedColor(&led_config, 0, WS2812_RED);
            setLedFlashing(&led_config, TRUE, 0);
            setLedTarget(&led_config, FALSE, LED_MODE_RED, 0);
            setLedTarget(&led_config, FALSE, LED_MODE_RED, 0);
            break;
    }
}

static THD_WORKING_AREA(waThreadMain, 1024);
static THD_FUNCTION(ThreadMain, arg) {

    (void)arg;

    events_init();
    scope_state_t         scope_state      = SCOPE_STATE_STOPPED;
    const scope_config_t *cfg              = NULL;
    systime_t             last_update_time = chVTGetSystemTimeX();

    while (true) {
        // chSemWait(&sem);
        msg_t evt = iqGetTimeout(&event_queue, TIME_MS2I(100));

        if ((chVTGetSystemTimeX() - last_update_time) > TIME_MS2I(200)) {
            last_update_time = chVTGetSystemTimeX();
            if (USBHTMCD[0].state == USBHTMC_STATE_ACTIVE) {
                usbDbgPrintf("TMC: Connected, TMC%d", 0);
                usbhtmcStart(&USBHTMCD[0]);
                cfg = detect_scope(&USBHTMCD[0]);
                if (!cfg) {
                    setLedColor(&led_config, 0, WS2812_RED);
                    setLedFlashing(&led_config, TRUE, 0);
                } else {
                    setLedColor(&led_config, 0, WS2812_BLUE);
                    setLedTarget(&led_config, TRUE, 0, 5000);
                }
                if (evt == MSG_TIMEOUT) {
                    evt = EVT_NOP;
                }
            } else if (USBHTMCD[0].state == USBHTMC_STATE_READY) {
                if (cfg) {
                    scope_state_t newstate;
                    if (!cfg->get_state(&USBHTMCD[0], &newstate)) {
                        setLedColor(&led_config, 0, WS2812_RED);
                        setLedFlashing(&led_config, TRUE, 0);
                    } else {
                        if (scope_state != newstate) {
                            scope_state = newstate;
                            if (evt == MSG_TIMEOUT) {
                                evt = EVT_NOP;
                            }
                        }
                    }
                }
            } else {
                setLedColor(&led_config, 0, WS2812_RED);
                setLedTarget(&led_config, TRUE, 0, 5000);
            }
        }
        if (evt == MSG_TIMEOUT) {
            continue;
        }

        chprintf((BaseSequentialStream *)&SD2, "evt = %d\r\n", evt);
        switch (evt) {
            case EVT_FOOTSW1_PRESS:
            case EVT_FOOTSW2_PRESS:
            case EVT_BTN_CLICK:
                if (USBHTMCD[0].state == USBHTMC_STATE_READY && cfg) {
                    scope_state_t newstate = SCOPE_STATE_STOPPED;
                    if (scope_state == SCOPE_STATE_STOPPED) {
                        if (palReadLine(LINE_MODE)) {
                            newstate = SCOPE_STATE_RUNNING;
                        } else {
                            newstate = SCOPE_STATE_SINGLE;
                        }
                    }
                    if (!cfg->set_state(&USBHTMCD[0], newstate)) {
                        setLedFlashing(&led_config, TRUE, 0);
                    } else {
                        scope_state = newstate;
                    }
                }
                break;
            case EVT_BTN_HOLD:
                usbhtmcIndicatorPulse(&USBHTMCD[0], NULL);
                break;

            default:
                break;
        }
        update_leds(scope_state);
    }
}



const struct image_header __attribute__((section(".header"))) image_header = {
    .magic = IMAGE_HEADER_MAGIC_INIT,
    .version_major = 1,
    .version_minor = 1,
    .version_patch = 0,
    .vid = 0x1d50, 
    .pid = 0x613b, 
    .bootloader_magic = {'F','T','S','W'},
    };

int main(void) {

    halInit();
    chSysInit();

    // PA2(TX) and PA3(RX) are routed to USART2
    sdStart(&SD2, NULL);

    chThdCreateStatic(waThreadLed, sizeof(waThreadLed), NORMALPRIO, ThreadLed,
                      0);
    chThdCreateStatic(waThreadMain, sizeof(waThreadMain), NORMALPRIO,
                      ThreadMain, 0);

    // turn on USB power
    palSetPad(GPIOA, GPIOA_HOST_VBUS_EN);
    chThdSleepMilliseconds(100);

    usbhStart(&USBHD1);

    for (;;) {
        usbhMainLoop(&USBHD1);

        chThdSleepMilliseconds(100);
    }
}

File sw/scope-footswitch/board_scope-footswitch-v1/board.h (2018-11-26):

/*
 * This file is part of the scope-footswitch project.
 *
 * Copyright (C) 2018 Paul Roukema <paul@paulroukema.com>
 *
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
 * You should have received a copy of the GNU General Public License
 * along with this program.  If not, see <http://www.gnu.org/licenses/>.
 */



#ifndef BOARD_H
#define BOARD_H

/*===========================================================================*/
/* Driver constants.                                                         */
/*===========================================================================*/

/*
 * Setup for STMicroelectronics STM32 Nucleo64-F401RE board.
 */

/*
 * Board identifier.
 */
#define BOARD_SCOPE_FOOTSWITCH_V1
#define BOARD_NAME                  "scope-footswitch_v1"

/*
 * Board oscillators-related settings.
 * NOTE: LSE not fitted.
 */
#if !defined(STM32_LSECLK)
#define STM32_LSECLK                0U
#endif

#if !defined(STM32_HSECLK)
#define STM32_HSECLK                8000000U
#endif

/*
 * Board voltages.
 * Required for performance limits calculation.
 */
#define STM32_VDD                   300U

/*
 * MCU type as defined in the ST header.
 */
#define STM32F401xE

/*
 * IO pins assignments.
 */
#define GPIOA_LED_DATA_LS           1U
#define GPIOA_UART_TX               2U
#define GPIOA_UART_RX               3U
#define GPIOA_MODE_LED_R            6U
#define GPIOA_MODE_LED_G            7U
#define GPIOA_HOST_VBUS_EN          9U
#define GPIOA_STM32_DM              11U
#define GPIOA_STM32_DP              12U
#define GPIOA_SWDIO                 13U
#define GPIOA_SWCLK                 14U

#define GPIOB_FOOTSW_BTN1           0U
#define GPIOB_FOOTSW_BTN2           1U
#define GPIOB_BOOT1                 2U
#define GPIOB_EN_DEVICE             5U
#define GPIOB_I2C_SCL               6U
#define GPIOB_I2C_SDA               9U
#define GPIOB_HOST_FAULT_N          15U

#define GPIOC_BTN                   13U
#define GPIOC_MODE                  14U

#define GPIOH_OSC_IN                0U
#define GPIOH_OSC_OUT               1U

/*
 * IO lines assignments.
 */
#define LINE_LED_DATA_LS            PAL_LINE(GPIOA, GPIOA_LED_DATA_LS)
#define LINE_UART_TX                PAL_LINE(GPIOA, GPIOA_UART_TX)
#define LINE_UART_RX                PAL_LINE(GPIOA, GPIOA_UART_RX)
#define LINE_MODE_LED_R             PAL_LINE(GPIOA, GPIOA_MODE_LED_R)
#define LINE_MODE_LED_G             PAL_LINE(GPIOA, GPIOA_MODE_LED_G)
#define LINE_HOST_VBUS_EN           PAL_LINE(GPIOA, GPIOA_HOST_VBUS_EN)
#define LINE_STM32_DM               PAL_LINE(GPIOA, GPIOA_STM32_DM)
#define LINE_STM32_DP               PAL_LINE(GPIOA, GPIOA_STM32_DP)
#define LINE_SWDIO                  PAL_LINE(GPIOA, GPIOA_SWDIO)
#define LINE_SWCLK                  PAL_LINE(GPIOA, GPIOA_SWCLK)

#define LINE_FOOTSW_BTN1            PAL_LINE(GPIOB, GPIOB_FOOTSW_BTN1)
#define LINE_FOOTSW_BTN2            PAL_LINE(GPIOB, GPIOB_FOOTSW_BTN2)
#define LINE_BOOT1                  PAL_LINE(GPIOB, GPIOB_BOOT1)
#define LINE_EN_DEVICE              PAL_LINE(GPIOB, GPIOB_EN_DEVICE)
#define LINE_I2C_SCL                PAL_LINE(GPIOB, GPIOB_I2C_SCL)
#define LINE_I2C_SDA                PAL_LINE(GPIOB, GPIOB_I2C_SDA)
#define LINE_HOST_FAULT_N           PAL_LINE(GPIOB, GPIOB_HOST_FAULT_N)

#define LINE_BTN                    PAL_LINE(GPIOC, GPIOC_BTN)
#define LINE_MODE                   PAL_LINE(GPIOC, GPIOC_MODE)

#define LINE_OSC_IN                 PAL_LINE(GPIOH, GPIOH_OSC_IN)
#define LINE_OSC_OUT                PAL_LINE(GPIOH, GPIOH_OSC_OUT)

/*===========================================================================*/
/* Driver pre-compile time settings.                                         */
/*===========================================================================*/

/*===========================================================================*/
/* Derived constants and error checks.                                       */
/*===========================================================================*/

/*===========================================================================*/
/* Driver data structures and types.                                         */
/*===========================================================================*/

/*===========================================================================*/
/* Driver macros.                                                            */
/*===========================================================================*/
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

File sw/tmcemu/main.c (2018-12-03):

/*
 * This file is part of the scope-footswitch project.
 *
 * Copyright (C) 2018 Paul Roukema <paul@paulroukema.com>
 *
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
 * You should have received a copy of the GNU General Public License
 * along with this program.  If not, see <http://www.gnu.org/licenses/>.
 */


#include <stdio.h>
#include <string.h>

#include "ch.h"
#include "hal.h"

#include "chprintf.h"

#include "usbcfg.h"
#include "scpi/scpi.h"

/*===========================================================================*/
/* Generic code.                                                             */
/*===========================================================================*/

/*
 * Red LED blinker thread, times are in milliseconds.
 */
static THD_WORKING_AREA(waThread1, 128);
static THD_FUNCTION(Thread1, arg) {

    (void)arg;
    chRegSetThreadName("blinker");
    while (true) {
        systime_t time;

        time = usbtmccfg.usbp->state == USB_ACTIVE ? 250 : 500;
        palClearLine(LINE_LED_BLUE);
        chThdSleepMilliseconds(time);
        palSetLine(LINE_LED_BLUE);
        chThdSleepMilliseconds(time);
    }
}

THD_FUNCTION(scpiThread, arg);

/*
 * Application entry point.
 */
int main(void) {

    /*
     * System initializations.
     * - HAL initialization, this also initializes the configured device drivers
     *   and performs the board-specific initializations.
     * - Kernel initialization, the main() function becomes a thread and the
     *   RTOS is active.
     */
    halInit();
    chSysInit();
    usb_init();

    /*
     * Initializes a serial-over-USB CDC driver.
     */
    tmcObjectInit(&TMC1);
    tmcStart(&TMC1, &usbtmccfg);

    /*
     * Activates the serial driver 1 using the driver default configuration.
     * PA9 and PA10 are routed to USART1.
     */
    sdStart(&SD1, NULL);
    palSetPadMode(GPIOA, 9, PAL_MODE_ALTERNATE(1));  /* USART1 TX.       */
    palSetPadMode(GPIOA, 10, PAL_MODE_ALTERNATE(1)); /* USART1 RX.       */

    /*
     * Activates the USB driver and then the USB bus pull-up on D+.
     * Note, a delay is inserted in order to not have to disconnect the cable
     * after a reset.
     */
    usbDisconnectBus(usbtmccfg.usbp);
    chThdSleepMilliseconds(1500);
    usbStart(usbtmccfg.usbp, &usbcfg);
    usbConnectBus(usbtmccfg.usbp);

    /*
     * Creates the blinker thread.
     */
    chThdCreateStatic(waThread1, sizeof(waThread1), NORMALPRIO, Thread1, NULL);

    /*
     * Normal main() thread activity, spawning shells.
     */
    while (true) {
        if (TMC1.config->usbp->state == USB_ACTIVE) {
            thread_t *tracetp = chThdCreateFromHeap(
                NULL, 4096, "trace", NORMALPRIO + 1, scpiThread, NULL);
            chThdWait(tracetp); /* Waiting termination.             */
        }
        chThdSleepMilliseconds(1000);
        chprintf((BaseSequentialStream *)&SD1, ".");
    }
}

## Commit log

2018-08-06 Initial add of HW
    [scope-footswitch.kicad_pcb, scope-footswitch.sch]
2018-08-06 Add project for USB host on Nucleo board
2018-08-06 Add kicad library tables
2018-08-11 Initial completion of schematic and layout
    [scope-footswitch.kicad_pcb, scope-footswitch.sch]
2018-08-13 PCB updates and output files
    [scope-footswitch-B.Cu.gbl, scope-footswitch-B.Mask.gbs, scope-footswitch-B.Paste.gbp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]
2018-08-16 Layout V1.1 Fix unconnected vias, pour under crystal, USB switch pads
    [scope-footswitch-B.Cu.gbl, scope-footswitch-B.Mask.gbs, scope-footswitch-B.Paste.gbp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]
2018-08-27 Initial implementation of USBTMC device Very basic, only handles small commands
2018-08-30 Updated kicad library version
2018-09-09 Switch chibios to v18.2 stable
2018-09-09 Initial version of target board code Basic USBTMC and UI operations working
2018-09-12 Fixes for DSO3034 compatibility
    [main.c]
2018-09-12 Improve tmc emulation, enable idn emulation based on target device
2018-09-12 Abstract scope command sets and add detection of attached device
2018-09-18 Fix buffer sizes for transfer oriented operation, compat with DSO9404A
    [main.c]
2018-11-14 HW Rev 13
    Tweak/DNP a bunch of parts to allow simplified power/boot control
    Update layout, including mechanical tweaks for better panel layout
    [scope-footswitch.kicad_pcb, scope-footswitch.sch]
2018-11-17 Update kicad library version
2018-11-17 Update kicad library to include readme
2018-11-17 Relocate kicad-library to github
2018-11-17 Switch to mainline ChibiOS-Contrib since USB fixes were merged
2018-11-19 Move/improve rev1.1 release structure
    [scope-footswitch-B.Cu.gbl, scope-footswitch-B.Mask.gbs, scope-footswitch-B.Paste.gbp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]
2018-11-19 Add notes about kicad-library setup process
2018-11-25 Rev 1.4, increase via hole size to 0.3mm
    [scope-footswitch-B.Cu.gbl, scope-footswitch-B.Mask.gbs, scope-footswitch-B.Paste.gbp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]
2018-11-26 Bootloader update: USB ID, flash size Switch to OpenMoko USB ID Correct flash size from 256K to 128K Add udev rule for user level flashing
2018-12-03 Fix missed license header
    [main.c]
2019-01-19 Improve LED flashing and reset behaviour of bootloader
    [main.c]

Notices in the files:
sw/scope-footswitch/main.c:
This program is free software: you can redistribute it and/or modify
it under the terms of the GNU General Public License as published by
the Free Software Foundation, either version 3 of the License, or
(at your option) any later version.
